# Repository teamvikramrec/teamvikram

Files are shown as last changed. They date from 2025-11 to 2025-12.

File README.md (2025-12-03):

# SUPER STAR
## Model Rocket Program by Team Vikram
### Rajalakshmi Engineering College

---

## About the Project

**SUPER STAR** represents Team Vikram's first fully student-driven model rocket initiative. We are a passionate collective of 30 engineering students from Rajalakshmi Engineering College, committed to designing, building, testing, and launching a fully functional model rocket—establishing the foundation for future advanced rocket programs.

This repository documents all technical subsystems, simulations, designs, analyses, and management workflows of the project.

> **Our Vision:** Build rockets. Build engineers. Build the future.

---

## About Team Vikram

Team Vikram is an interdisciplinary student rocketry team advancing hands-on aerospace engineering and research. Our focus areas include:

- Practical engineering experience through project-based learning
- End-to-end rocket system development
- Collaborative teamwork and leadership development
- Open-source project documentation
- Innovation in propulsion, avionics, and data systems

---

## Repository Structure

This GitHub repository contains comprehensive documentation for the SUPER STAR project, organized into four technical subsystems and two management subsystems:

```
SUPER-STAR/
├── Avionics & Telemetry/
├── Aerodynamics & Structures/
├── Propulsion & Fuel System/
├── Simulation & Software/
└── README.md
```

---

## Technical Subsystems

### 1. Avionics & Telemetry

The **Avionics & Telemetry** subsystem serves as the "brain" of the rocket, ensuring stable flight, safety protocols, and real-time monitoring capabilities.

**Core Responsibilities:**
- Flight Computer (FC) design and development
- Sensor interfacing: IMU, barometer, gyroscope
- Telemetry transmission systems: LoRa/WiFi/Radio
- Power management and PCB integration
- Recovery system logic and parachute deployment triggers
- Data logging and post-flight analysis
- Ground station software integration

---

### 2. Aerodynamics & Structures

This subsystem focuses on rocket design optimization, aerodynamic performance, and structural integrity.

**Core Responsibilities:**
- Airframe design and development
- Fin geometry and stability analysis
- Nose cone shaping for drag reduction
- Material selection: PLA, composites, metal, carbon fiber
- Thrust-to-weight ratio calculations
- Center of Gravity (CG) and Center of Pressure (CP) positioning
- Structural analysis using Finite Element Analysis (FEA)
- Manufacturing oversight and quality assurance

**Deliverables:**
- Detailed CAD models
- Stress test reports
- Stability margin calculations
- Material performance analysis

---

### 3. Propulsion & Fuel System

This subsystem develops and validates the propulsion system for the model rocket.

**Core Responsibilities:**
- Sugar-based solid rocket motor design
- Propellant grain casting and configuration
- Nozzle design: material selection and geometry optimization
- Thrust measurement and performance testing
- Motor casing and thermal insulation
- Fuel safety protocols and handling procedures
- Burn rate and chamber pressure analysis

**Testing Protocols:**
- Static fire testing
- Thrust data acquisition and analysis
- Nozzle erosion studies
- Performance validation

---

### 4. Simulation & Software

This team performs comprehensive simulations, code development, and system testing.

**Core Responsibilities:**
- Flight simulation using OpenRocket, MATLAB, and Python
- Aerodynamic performance modeling
- Trajectory prediction and optimization
- Stability simulation and analysis
- Telemetry dashboard and ground-station GUI development
- Flight computer control loop software
- Failure mode simulation and risk modeling

---

## Management Subsystems

### 5. Media & Research Documentation

This subsystem ensures comprehensive documentation and effective outreach.

**Core Responsibilities:**
- Technical documentation maintenance
- Design of posters, videos, and event media
- Research report compilation
- GitHub repository management
- Outreach content creation for junior recruitment
- Event presentations and competition documentation

---

### 6. Finance & Sponsorship

This subsystem manages the financial infrastructure of the project.

**Core Responsibilities:**
- Budget planning and allocation
- Expense tracking and financial reporting
- Component sourcing and procurement
- Sponsor acquisition and partnership development
- Sponsorship proposal preparation
- Competition financial documentation

---

## Project Milestones

### Short-Term Goals
- Design, build, and launch the SUPER STAR model rocket
- Complete comprehensive subsystem documentation
- Conduct static thrust testing
- Achieve reliable telemetry and recovery system operation
- Train junior members for future missions

### Long-Term Goals
- Develop advanced high-power rocket systems
- Participate in national and international rocketry competitions
- Design custom avionics boards
- Research hybrid and liquid propulsion systems

---

## Documentation Roadmap

**Planned Additions:**
- [ ] Complete flight computer schematics
- [ ] Thrust test results and analysis
- [ ] CAD models for all components
- [ ] Simulation graphs and performance data
- [ ] Subsystem team member lists
- [ ] Competition presentations and results
- [ ] Recovery system detailed design

---

## Contributing

Members of Team Vikram can contribute by pushing subsystem documentation to this repository. Please follow the structure and naming conventions outlined in each folder's guidelines.

---

## Contact & Collaboration

For inquiries, collaboration opportunities, or sponsorship proposals, please reach out to Team Vikram through our official channels.

---

<div align="center">

### "Small teams build small rockets. Big dreams build rocket teams."

**Team Vikram | Rajalakshmi Engineering College**

*Building the future, one launch at a time.*

</div>

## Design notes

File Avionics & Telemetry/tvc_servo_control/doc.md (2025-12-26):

# ESP32 TVC Flight Controller

A lightweight active stabilization system for model rockets using Thrust Vector Control (TVC). This firmware runs on an ESP32, processing data from an MPU6050 IMU to adjust the angle of the rocket motor gimbal via two servos, keeping the vehicle vertical during ascent.

## 🚀 Features
* **Sensor Fusion:** Implements a **Complementary Filter** (Alpha 0.98) to combine Accelerometer and Gyroscope data for drift-free, responsive angle estimation.
* **PD Control Loop:** Proportional-Derivative controller to correct orientation errors.
* **Servo Constraints:** Safety limits (`SERVO_LIMIT`) prevent the TVC mount from binding or over-extending.
* **High Performance:** Runs at approximately 200Hz loop frequency.

## 🛠️ Hardware Requirements
* **Microcontroller:** ESP32 Development Board
* **IMU:** MPU6050 (6-axis Accelerometer/Gyroscope)
* **Actuators:** 2x Servos (e.g., SG90, MG90S) connected to a TVC Mount
* **Power:** 5V BEC or Battery appropriate for servos

## 🔌 Wiring / Pinout

| Component | Pin Label | ESP32 Pin |
| :--- | :--- | :--- |
| **Servo Pitch (Y)** | Signal | `GPIO 18` |
| **Servo Roll (X)** | Signal | `GPIO 19` |
| **MPU6050** | SDA | `GPIO 21` |
| **MPU6050** | SCL | `GPIO 22` |
| **MPU6050** | VCC | 3.3V or 5V |
| **MPU6050** | GND | GND |

> **Note:** Ensure the Servos and ESP32 share a common Ground (GND).

## 📦 Software Dependencies
You must install the following library via the Arduino Library Manager:

1.  **ESP32Servo** by Kevin Harrington

## ⚙️ Configuration & Tuning

Parameters in the code can be adjusted to fit your specific airframe:

### 1. Servo Alignment
* **`SERVO_CENTER` (Default: 90):** The servo angle where the motor is perfectly straight.
* **`SERVO_LIMIT` (Default: 12):** The maximum number of degrees the motor can tilt in either direction.

### 2. PID Tuning
The controller uses a PD loop to maintain stability.
* **`Kp` (Proportional):** Reacts to the current angle error. Increase if the rocket is sluggish to correct; decrease if it oscillates rapidly.
* **`Kd` (Derivative):** Reacts to the *rate* of change. Acts as a "damper" to prevent overshooting.

```cpp
// Control gains (TUNE CAREFULLY)
float Kp = 1.5;   // Start LOW and increase
float Kd = 0.05;  // Dampening factor

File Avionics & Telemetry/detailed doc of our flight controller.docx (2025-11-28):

SYSTEM OVERVIEW:

The Flight Computer (FC) serves as the "brain" of the launch vehicle. Its primary objective is to maintain vertical stability during the boost phase using Thrust Vector Control (TVC), record flight data, and execute recovery events.

Core Functions:

- Stabilization: Active TVC using servo-actuated motor gimbaling.
- Data Logging: High-frequency recording of altitude, acceleration, and orientation.
- Event Triggering: Apogee detection and parachute deployment.
- Telemetry: Real-time air-to-ground data transmission for monitoring flight status.

Final Component Selection Rationale

The following components constitute the final BOM.

1.1 Flight Controller

- Component: ESP32 Development Module
- Role: Central processing unit for TVC, deployment, and telemetry.
- Justification: High-speed dual-core processor essential for running complex stabilization algorithms without loop-time lag.

1.2 Sensors (Navigation & Environment)

- LSM6DSO32 (6-DOF Accelerometer & Gyroscope)
  - Role: Primary orientation sensor for TVC.
  - Justification: This is a high-performance industrial-grade sensor, offering superior stability and noise immunity compared to the older MPU6050.
- ICM-20602 or MPU6050
  - Role: Redundancy or filtering verification.
- Altimeter: BMP280 or BMP390
  - Role: Measures altitude to detect apogee (highest point).
  - Justification: Crucial for the recovery system. It triggers the parachute when it detects the rocket is descending (altitude drops for 5 consecutive readings).
- High-G Accelerometer: ADXL345 or ADXL377 (Optional)
  - Role: Detecting liftoff and measuring peak G-force.
  - Justification: Standard IMUs often "clip" (max out) at 16g. A High-G accelerometer (up to 200g) ensures we capture the true force of the motor burn.

1.3 Telemetry & Data Logging

- Telemetry: LoRa SX1278 Module (433MHz)
  - Role: Real-time air-to-ground data transmission.
  - Justification: Superior to HC-12. LoRa offers long-range capabilities (3-5 km) and excellent noise immunity, ensuring we receive data even if the rocket spins or tumbles.
- Data Logging: Micro SD Card Module
  - Role: "Black Box" recording.
  - Justification: Wireless telemetry can drop packets. Onboard logging saves data at a high frequency for post-flight analysis.

1.4 Actuators (Motion Control)

- Servos: 3x Metal Gear Servos (MG90S or DS929)
  - Usage:
    - 2x for TVC: Gimbaling the motor nozzle for stability.
    - 1x for Recovery: Actuating the parachute release door/mechanism.
  - Justification: Metal gears are mandatory. Plastic gears will strip under the vibration and aerodynamic loads of launch.

1.5 Power System

- Battery: LiPo (7.4V 2S or 12V 3S)
  - Role: Main power source.
- Buck Converter:
  - Role: Steps down high LiPo voltage to a stable 5V or 6V.
  - Justification: Servos need high current at 5V-6V. Powering them directly from the ESP32 is impossible (it would fry the board), and powering them directly from a 12V LiPo would destroy the servos.

2. Static Test Equipment (Ground Support)

- Load Cell: 50kg or 100kg
- Amplifier: HX711
- Role: Measuring Peak Thrust, Burn Time, and Total Impulse during the ground fire test. This data generates the Thrust Curve needed for flight simulations.

3. Architecture Update: Transition to ESP32

Decision: The Flight Computer architecture is upgraded from a Dual Arduino Nano setup to a Single ESP32 Development Board.

3.1 Why the Change?

Initially, the design proposed two Arduino Nanos (one for control, one for data) to handle 5V logic compatibility. However, the ESP32 has been selected as the final choice for the following reasons:

- Processing Power: The ESP32 operates at 240 MHz (Dual Core) compared to the Arduino Nano's 16 MHz. This allows for faster PID loop calculations required for stable Thrust Vector Control (TVC) while simultaneously logging data.
- Unified System: A single board reduces internal volume, weight, and failure points (wiring) compared to the "2 Nano architecture"².

Voltage Logic: Most modern sensors (LSM6DSO32, BMP280, SD Cards) operate natively on 3.3V. Using an ESP32 eliminates the need for level shifters that would be required with a 5V Arduino Nano.

# STATIC TEST:

1. Introduction and Objectives

The Static Fire Test is the critical validation phase of the propulsion system. In this test, the rocket motor is ignited while securely restrained to a ground test stand. The primary objectives are:

1. Characterize Propulsion: To measure the Thrust Curve, Peak Thrust, and Total Impulse to verify the motor meets the mission profile.
2. Validate Avionics: To test the "Dual Nano" setup under high-vibration conditions without risking flight hardware.
3. Verify Mechanical Integrity: To ensure the Thrust Vector Control (TVC) mounts and gimballing system can withstand the force of firing.

2. Theoretical Framework

To interpret the test results, the following parameters are defined:

2.1 Thrust Generation and Curve

Thrust is the reaction force described by Newton’s Third Law. The Thrust Curve is a graphical representation of this force over time.

- X-Axis: Time (t) in seconds.
- Y-Axis: Force (F) in Newtons.
- Key Phases: The curve displays the Ignition Transient (spike), Steady State (burn), and Tail-off (pressure drop).

2.2 Impulse Calculations

- Total Impulse: Represents the total energy capacity of the motor, used to classify the motor (Class A, B, C, etc.). It is calculated by integrating the area under the thrust curve:
- Specific Impulse : Measures fuel efficiency (push produced per unit of fuel mass):

(g0 = 9.81 m/s2)

3. Experimental Setup (Hardware & Electronics)

The setup is divided into the Ground Station (Force Measurement) and the Onboard Avionics (Vibration & TVC Validation).

3.1 Ground Test Stand (Thrust Measurement)

Since the onboard accelerometer cannot measure thrust when the rocket is clamped stationary, an external sensor system is required.

- Mechanical Frame: A rigid wooden or metal sled design that clamps the rocket motor horizontally or vertically, allowing for slight axial sliding against the sensor.
- Sensor (Load Cell): A single-point load cell rated for 150% of expected peak thrust (e.g., for a 100N motor, use a 20kg/200N cell) to prevent sensor saturation.
- Amplifier: An HX711 module is used to amplify the millivolt signal from the load cell for the microcontroller.
- Data Logger: An Arduino UNO (distinct from the flight computer) connected via USB to a laptop running a Serial Plotter.
- Sampling Rate: Minimum 80Hz (recommended 100Hz+) to capture the rapid ignition spike.

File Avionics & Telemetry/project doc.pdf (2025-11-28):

# Technical Document: Avionics and Telemetry Overview

This document details the technical setup for a rocket's flight computer and the essential pre-flight parameters.

## Flight Computer (FC) Overview

A Flight Computer (FC) is the brain of the rocket. It reads the rocket's motion using sensors and makes decisions in real time.

The proposed architecture uses a single ESP to handle all functions:
TVC, data collection, parachute ejection, and telemetry.

Consolidated Components

The single ESP handles all core systems:

- TVC and Stabilization
The ESP controls the Thrust Vector Control system using:
- IMU Sensor: ICM-20602 or MPU6050
- Two Metal Gear Servos: MG90S / DS929
- Buck Converter: (6V → 5V, adjusted for ESP requirements)
- Servo Power Supply: 5V–6V, 2–3A
- Data and Ejection
The ESP collects data from:
- Barometric Sensor: BMP280
- Optional High-G Accelerometer: ADXL345
- Data logging: Micro SD Card Module + SD Card (8–32 GB)
- Parachute Ejection:

■ Micro servo

## Flight Computer Basic Functions

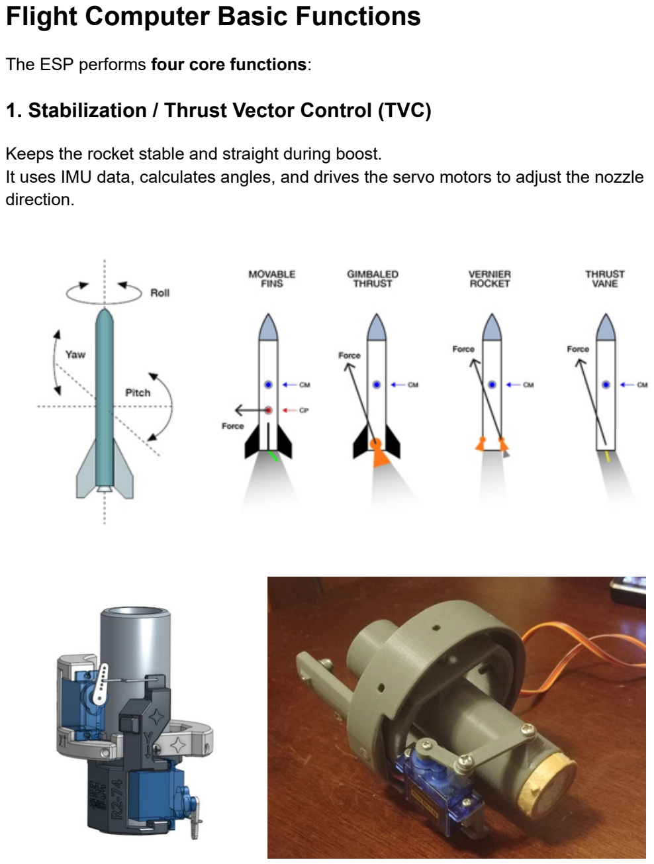
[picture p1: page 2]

The ESP performs four core functions:

### 1. Stabilization / Thrust Vector Control (TVC)

Keeps the rocket stable and straight during boost.
It uses IMU data, calculates angles, and drives the servo motors to adjust the nozzle direction.

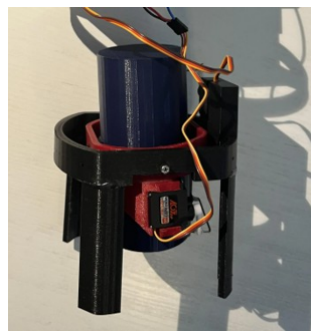
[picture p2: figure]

### 2. Data Logging

Records parameters including:

- Acceleration
- Altitude
- Orientation
- Temperature
- Velocity

All data is saved to an SD card for post-flight analysis.

### 3. Event Triggering

Detects apogee (highest point) and triggers the parachute deployment system.

### 4. Telemetry

Sends live flight data to the ground using the LoRa module.

## Parachute System

The ESP detects apogee and initiates parachute release.

Apogee Detection Method

1. Read altitude from the barometer.

2. If altitude decreases for 5 consecutive readings, the ESP confirms that the rocket is falling.
3. The parachute deployment mechanism is fired.

Parachute Deployment Methods

Options include:

- Servo-based door release

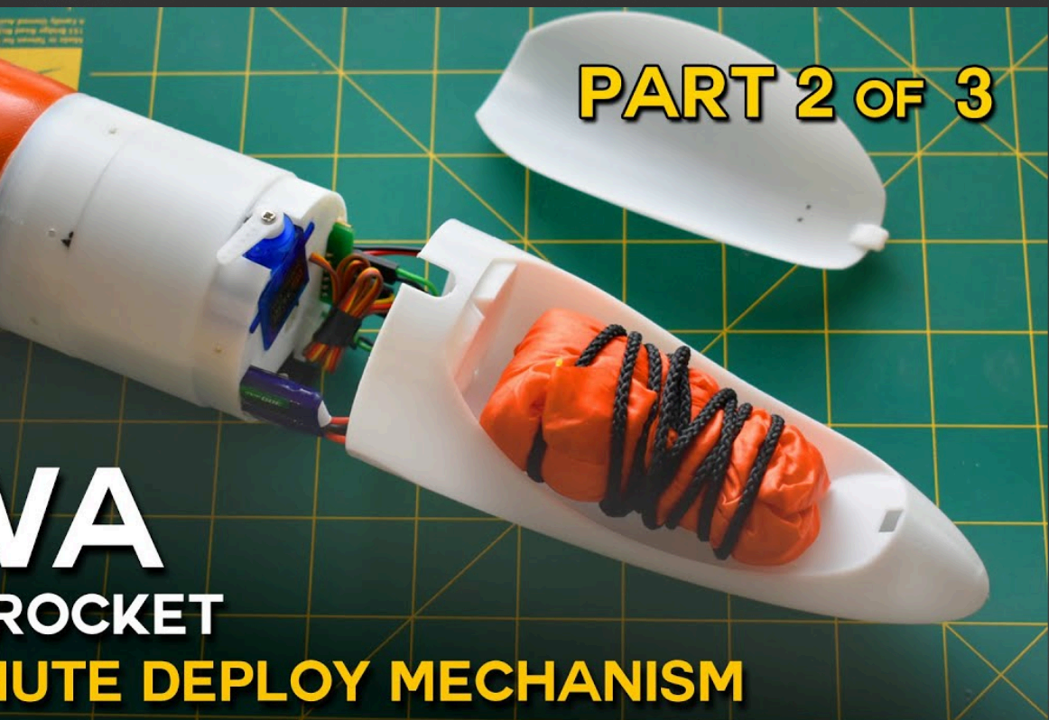
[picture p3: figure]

## LoRa Telemetry (Air-to-Ground Communication)

Telemetry sends live data from the rocket to the ground during flight.
The LoRa SX1278 module (Ra-02) is selected.

Key Specifications

- Long Range: 3–5 km with small antennas
- Noise Immunity: Very high
- Power: Low power consumption
- Stability: Works even if the rocket spins or rotates

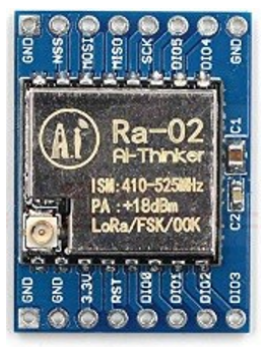
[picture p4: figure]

Benefits for Testing

- TVC Verification:
Live angle readings show if the stabilization loop is performing correctly.
- Failure Detection:
Detect servo stall, battery drop, sudden spin, or other mid-flight anomalies.
- Performance Analysis:
Helps validate:
- Thrust curve
- Angle behavior
- Apogee point
- Servo response
- Flight stability

## Reference Links

- Thrust-Vector Control Mount (design team): https://youtu.be/KJJ0bbHzJx8
- Reference video (using Nano): https://youtu.be/MYdrzulL2zY
- Parachute ejection mechanism: https://youtube.com/shorts/HQN6HNjEQvc

- Parachute ejection mechanism (full video): https://youtu.be/COkh5ykzC3Y

# Parameter need to check before flight

Motor testing
Structural testing
Avionics (electronics) testing Safety testing

### 1. MOTOR / THRUST TESTING PARAMETERS

- Peak Thrust (N)

Maximum force your motor produces.
- Average Thrust (N)

Needed for stability calculation and simulation.
- Burn Time (seconds)

How long the motor produces thrust.
- Pressure Build-up

Check if nozzle gets clogged or pressure spikes.
- Thrust Curve

Plot: Thrust vs Time → needed for flight simulation.
- Total Impulse (Ns)

Tells the motor class (A, B, C, D,
etc.) Formulae Integral of thrust
over time
- Pre-ignition safety

Check if propellant burns smoothly during ignition.

Component needed

- Load Cell (50 kg or 100 kg)
- Load Cell Amplifier (HX711)

Reference:

https://youtube.com/shorts/xvaB1OYGh7c?si=hh4LE6Wpibh1NK8G

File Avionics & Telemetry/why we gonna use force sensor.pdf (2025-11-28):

Force Sensor Usage in Rocket Launches

1. What is a Force Sensor?

A force sensor measures how much force is applied. In rocket applications,

it is normally used to measure thrust — the pushing force of the engine.

Common sensors include load cells, strain gauges, and thrust stand sensors.

2. Is a Force Sensor Needed for Rocket Flight?

No. A force sensor is not mounted on the rocket during flight because it

adds weight, can break due to vibration and heat, and provides no benefit

during actual launch. Rockets in flight usually carry sensors like GPS,

IMU, and pressure sensors, not force sensors.

3. Is a Force Sensor Needed for Ground Testing?

Yes. Force sensors are essential for static fire testing of rocket motors.

They measure:

- Peak thrust
- Thrust curve (thrust vs. time)
- Burn time
- Total impulse
- Engine stability

This information ensures the motor is safe and powerful enough for launch.

4. Common Student-Level Setup

A 50 kg or 100 kg load cell with an HX711 amplifier module connected to

an Arduino or ESP32 is typically used to build a thrust stand.

5. Summary
- Not required on the rocket during flight.

- Essential on the ground for testing the engine before launch.

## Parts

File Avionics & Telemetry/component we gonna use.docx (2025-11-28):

Component List (Internal)

- ESP32 dev module
- Micro SD Card Module.
- IMU (ICM-20602/MPU6050) and Barometer (BMP280/390).
- High-G Accelerometer (ADXL345 / ADXL377) — optional
- LiPo Battery – 7.4V / 12V.
- LoRa SX1278 module
- LSM6DSO32 - 6 DOF Accelerometer and Gyroscope Sensor
- 3 Metal Gear Servos (MG90S or DS929)
- Load cell - HX711 amplifier
- Buck Converter

PARTS THAT SHOULD BE DESIGNED :

1. Recovery System (Parachute Ejection)

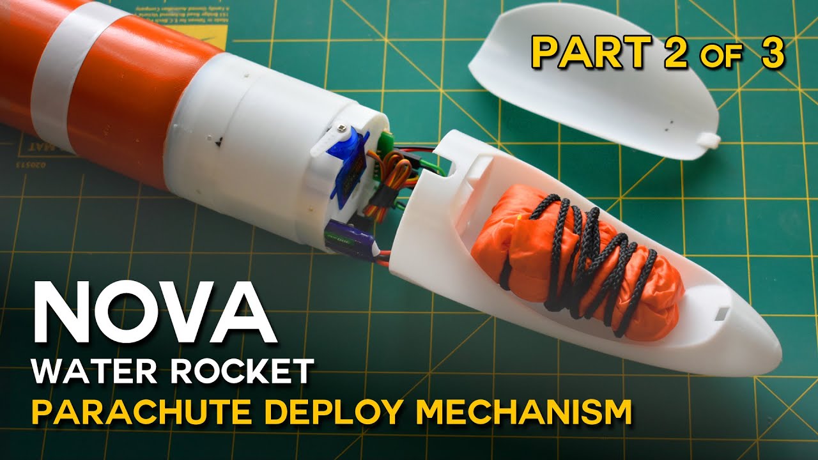
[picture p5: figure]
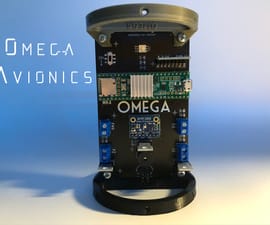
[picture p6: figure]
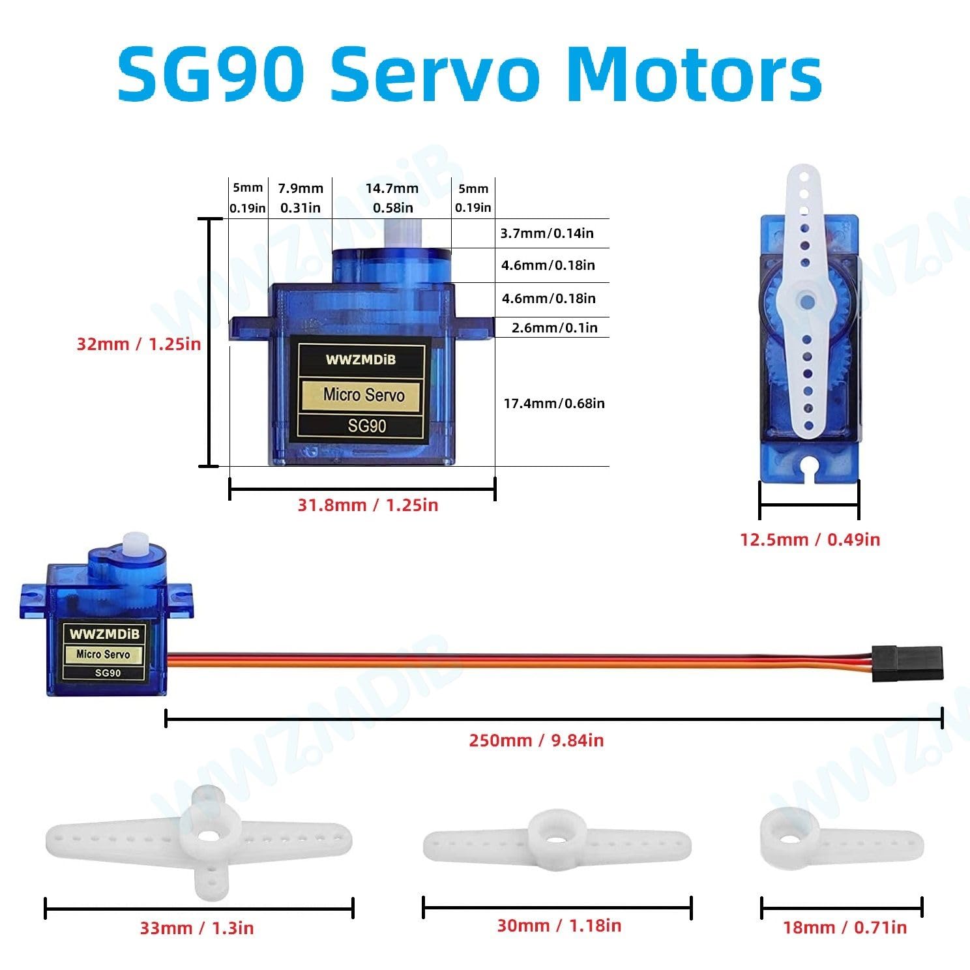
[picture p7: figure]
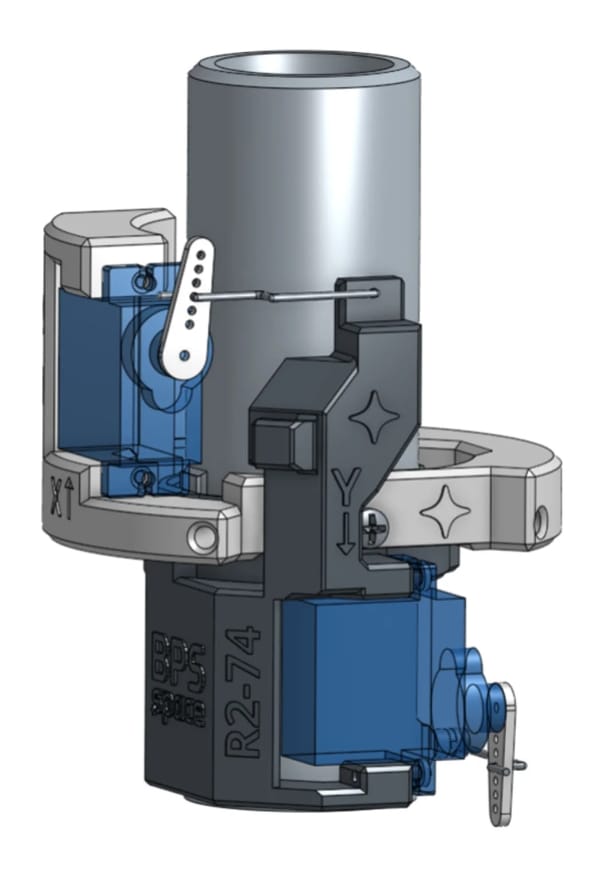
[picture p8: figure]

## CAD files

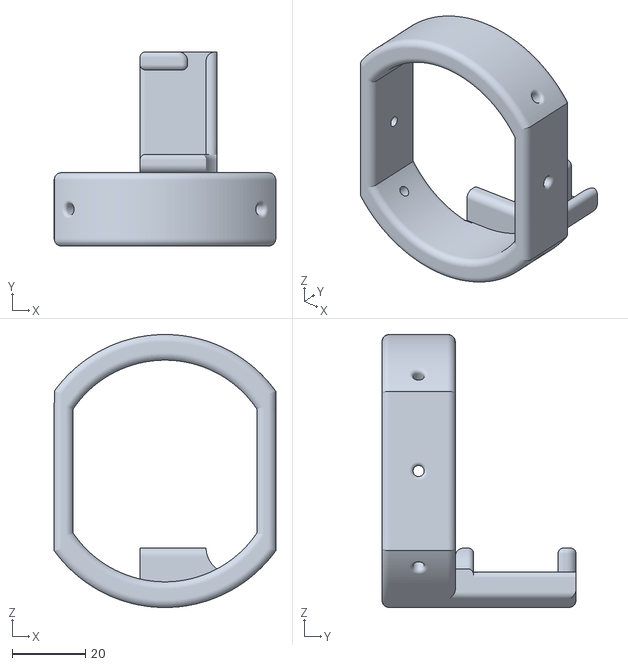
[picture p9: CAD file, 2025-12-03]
Avionics & Telemetry/test 3d model/Outer.stl
60.4 x 52.9 x 74.4

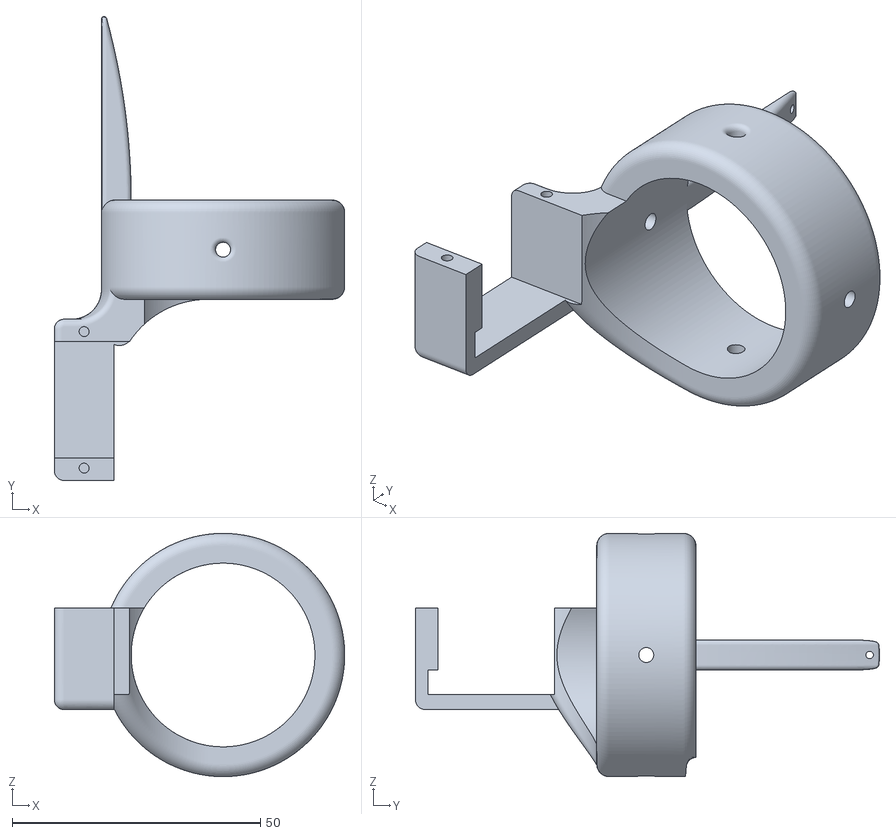
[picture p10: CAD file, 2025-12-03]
Avionics & Telemetry/test 3d model/Inner Mount.stl
58.5 x 93.5 x 49.0

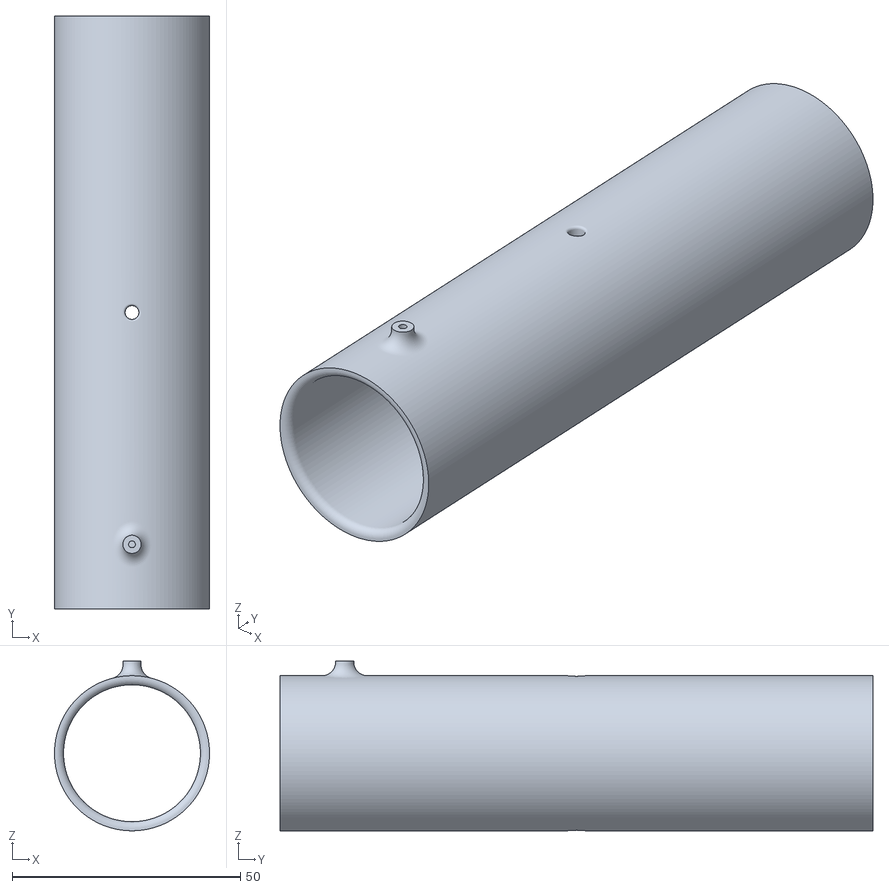
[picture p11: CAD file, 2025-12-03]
Avionics & Telemetry/test 3d model/MotorTube.stl
34.0 x 130.0 x 37.2

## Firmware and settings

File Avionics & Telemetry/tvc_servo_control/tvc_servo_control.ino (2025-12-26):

#include <Wire.h>
#include <ESP32Servo.h>

#define MPU_ADDR 0x68


#define SERVO_PITCH_PIN 18
#define SERVO_ROLL_PIN  19


Servo servoPitch;
Servo servoRoll;


int16_t ax, ay, az;
int16_t gx, gy, gz;


float ax_g, ay_g, az_g;
float gx_dps, gy_dps;


float pitch_acc, roll_acc;
float pitch = 0, roll = 0;

// Timing
unsigned long prevTime;
float dt;

// Complementary filter
#define ALPHA 0.98

// Servo settings
#define SERVO_CENTER 90
#define SERVO_LIMIT  12    // max correction (+/- degrees)

// Control gains (TUNE CAREFULLY)
float Kp = 1.5;   // start LOW
float Kd = 0.05;


float prevPitchError = 0;
float prevRollError  = 0;

void setup() {
  Serial.begin(115200);
  Wire.begin(21, 22);

 
  Wire.beginTransmission(MPU_ADDR);
  Wire.write(0x6B);
  Wire.write(0x00);
  Wire.endTransmission(true);

  servoPitch.attach(SERVO_PITCH_PIN);
  servoRoll.attach(SERVO_ROLL_PIN);

  servoPitch.write(SERVO_CENTER);
  servoRoll.write(SERVO_CENTER);

  delay(2000);
  prevTime = millis();

  Serial.println("TVC Controller Ready");
}

void loop() {
  unsigned long currentTime = millis();
  dt = (currentTime - prevTime) / 1000.0;
  prevTime = currentTime;

  Wire.beginTransmission(MPU_ADDR);
  Wire.write(0x3B);
  Wire.endTransmission(false);
  Wire.requestFrom(MPU_ADDR, 14, true);

  ax = Wire.read() << 8 | Wire.read();
  ay = Wire.read() << 8 | Wire.read();
  az = Wire.read() << 8 | Wire.read();
  Wire.read(); Wire.read(); // temp
  gx = Wire.read() << 8 | Wire.read();
  gy = Wire.read() << 8 | Wire.read();
  gz = Wire.read() << 8 | Wire.read();


  ax_g = ax / 16384.0;
  ay_g = ay / 16384.0;
  az_g = az / 16384.0;

  gx_dps = gx / 131.0;
  gy_dps = gy / 131.0;


  roll_acc  = atan2(ay_g, az_g) * 180 / PI;
  pitch_acc = atan2(-ax_g, sqrt(ay_g * ay_g + az_g * az_g)) * 180 / PI;


  roll  = ALPHA * (roll + gx_dps * dt) + (1 - ALPHA) * roll_acc;
  pitch = ALPHA * (pitch + gy_dps * dt) + (1 - ALPHA) * pitch_acc;


  float pitchError = -pitch;
  float rollError  = -roll;


  float pitchRate = (pitchError - prevPitchError) / dt;
  float rollRate  = (rollError - prevRollError) / dt;

  prevPitchError = pitchError;
  prevRollError  = rollError;

  float pitchCmd = Kp * pitchError + Kd * pitchRate;
  float rollCmd  = Kp * rollError  + Kd * rollRate;


  pitchCmd = constrain(pitchCmd, -SERVO_LIMIT, SERVO_LIMIT);
  rollCmd  = constrain(rollCmd,  -SERVO_LIMIT, SERVO_LIMIT);


  servoPitch.write(SERVO_CENTER + pitchCmd);
  servoRoll.write(SERVO_CENTER + rollCmd);

  Serial.print("Pitch: "); Serial.print(pitch);
  Serial.print(" | Roll: "); Serial.print(roll);
  Serial.print(" | SP: "); Serial.print(SERVO_CENTER + pitchCmd);
  Serial.print(" | SR: "); Serial.println(SERVO_CENTER + rollCmd);

  delay(5); // ~200 Hz
}

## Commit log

2025-12-03 added test 3d model for tvc
    [Inner Mount.stl, MotorTube.stl, Outer.stl]
2025-12-26 Add ESP32 TVC Flight Controller firmware and documentation
